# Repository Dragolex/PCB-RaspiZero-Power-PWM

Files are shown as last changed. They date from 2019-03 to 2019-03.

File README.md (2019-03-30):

# PCB-RaspiZero-Power-PWM
My first mostly successful try at a printed circuit board. It hosts a PCA9685 16xPWM generator and mosfets for every channel.
Controled via I2C from a Raspberry PI or an Adruino it can be used to dim loads of 7A and more. 
The board's shape, pins and hole palcement equals a Raspberry Pi Zero and therefore allows to mount it directly ontop and still use all pins.  
The Mosfets are N channel mosfets meaning only the Ground is common for all of them and on the PCB. Therefore loads of different voltages can be used simultaneously.

**The project can be opened with Eagle 9.1.1 or newer (importing into odler versions should be possible too).**

Boards based on Gerber files exported from this project have been produced by https://jlcpcb.com/
Samples have been soldered by myself and tested successfully with a bunch of different loads. Unfortunately it turned out that the diodes on the backside of the PCB are efectively useless because not sensefully placed in the scheme. Therefore inductive loads like motors still require separate flyback diodes!

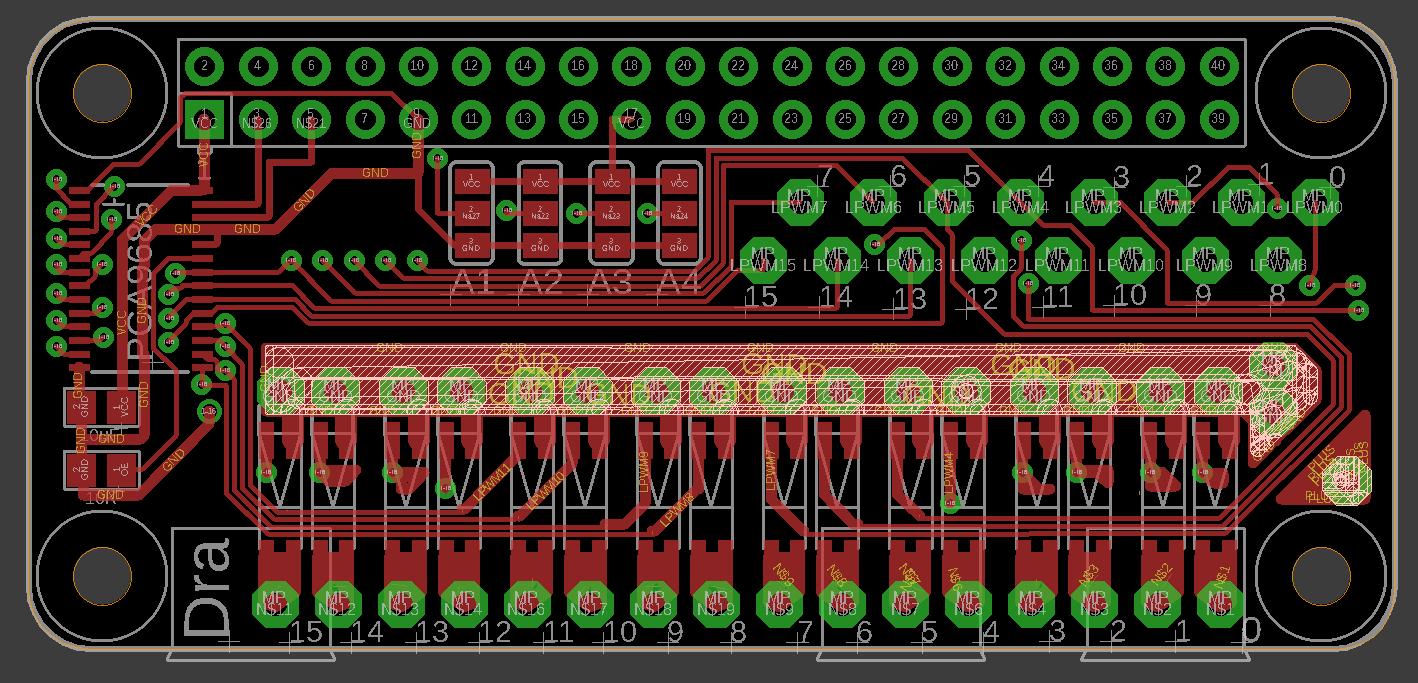
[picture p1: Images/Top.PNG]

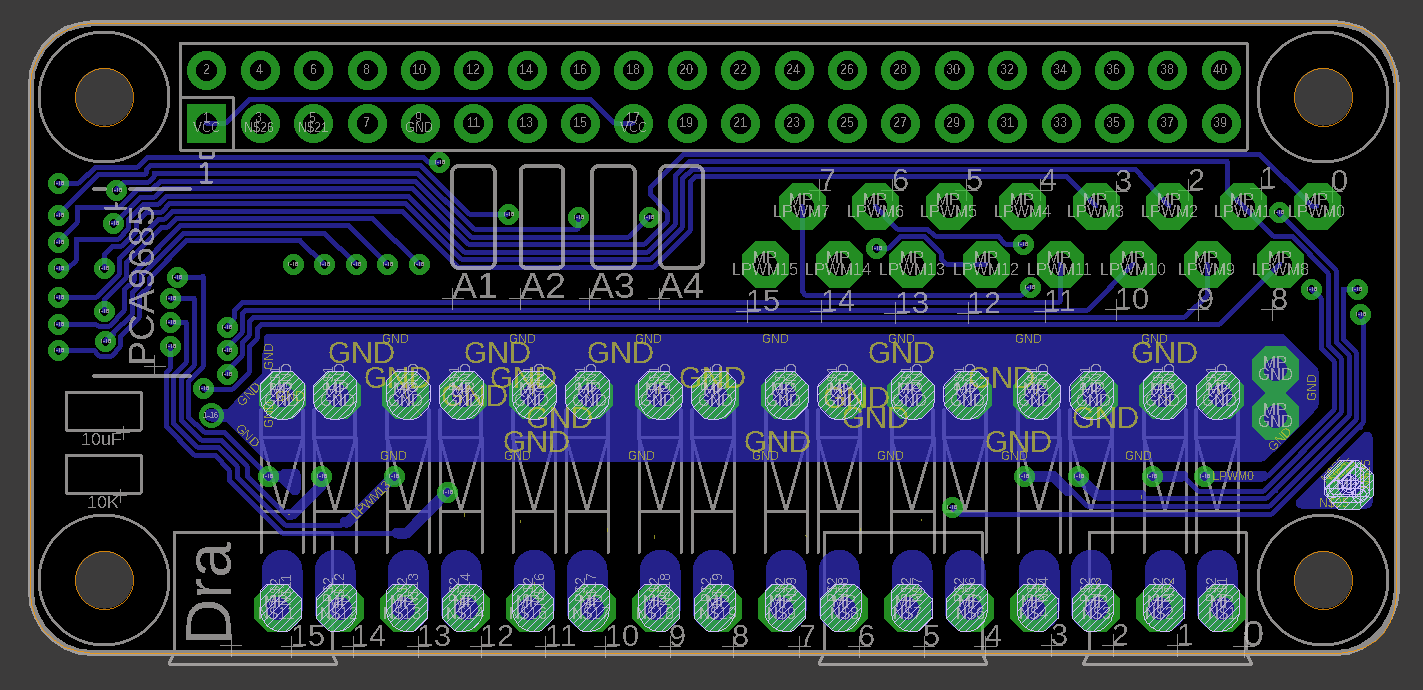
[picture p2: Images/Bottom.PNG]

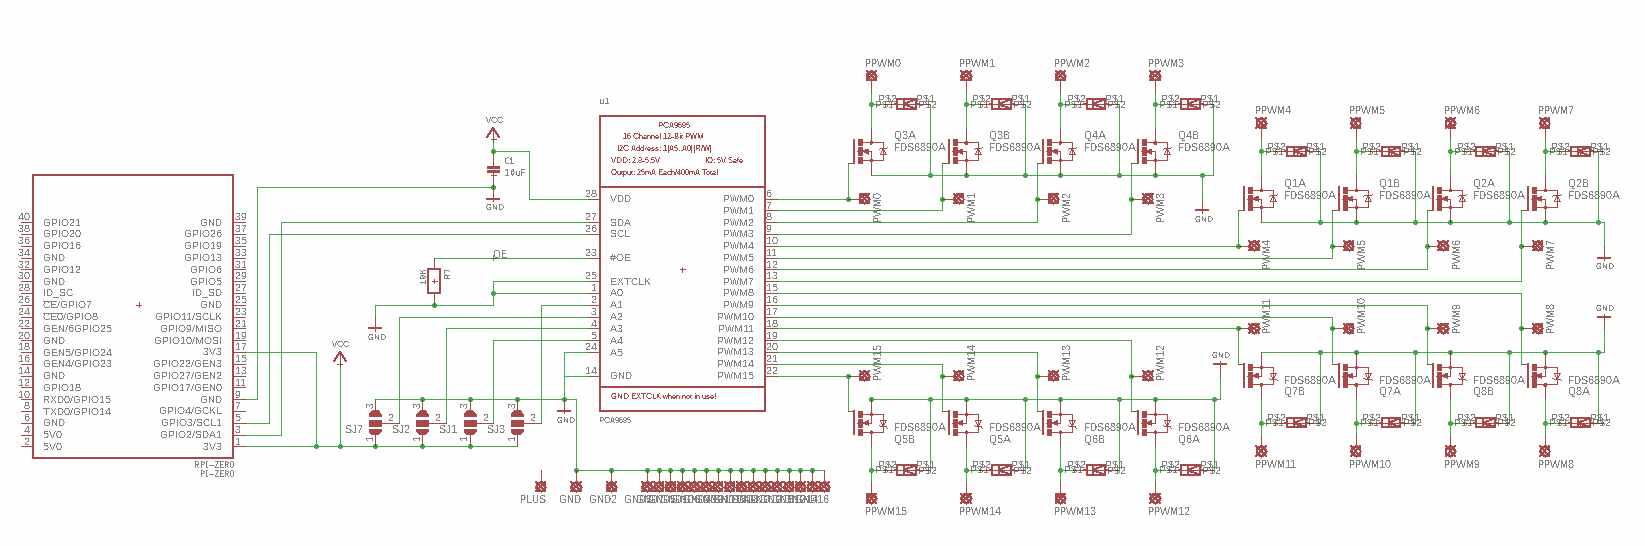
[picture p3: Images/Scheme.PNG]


Photos of a project using this comes soon.

## Credits
The PCA9685 and Raspberry scheme footprints are from Adafruit:
https://learn.adafruit.com/16-channel-pwm-servo-driver/downloads

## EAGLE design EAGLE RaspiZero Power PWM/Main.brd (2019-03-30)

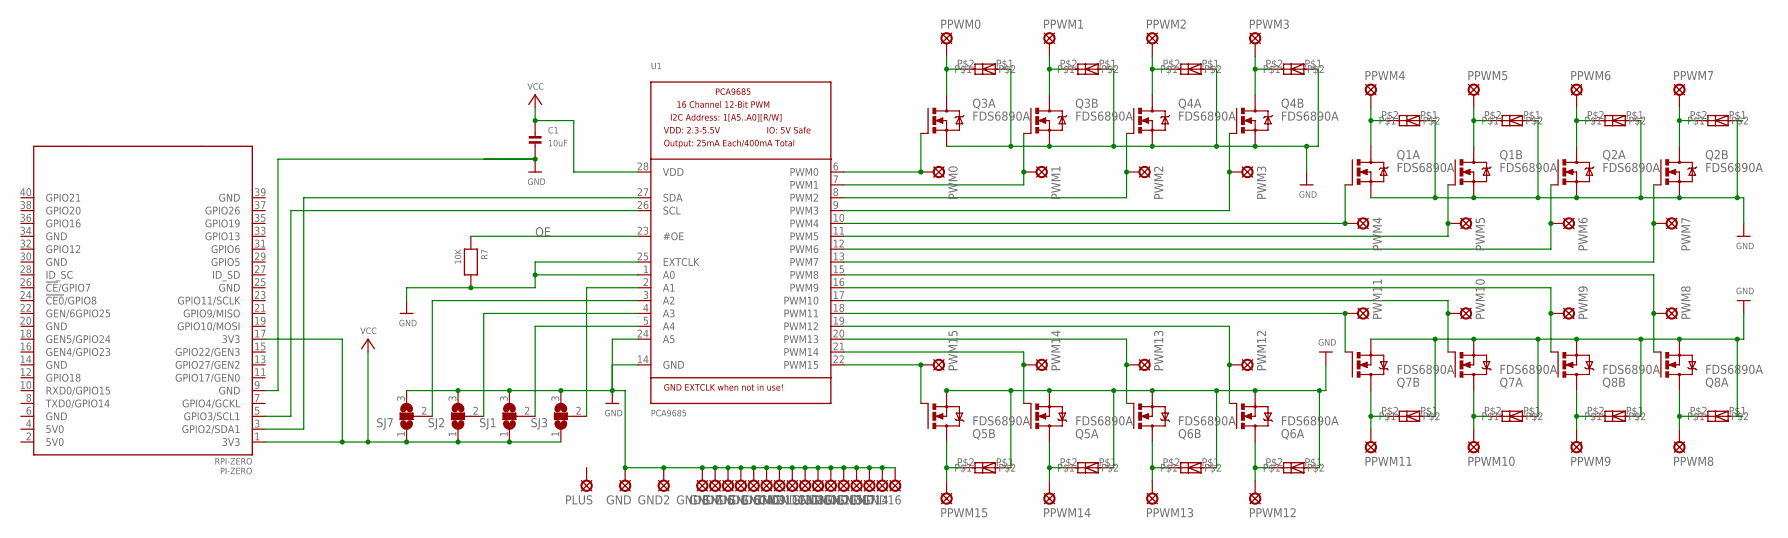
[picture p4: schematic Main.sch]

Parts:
C1: 10uF; 0805
GND, GND1, GND2, GND3, GND4, GND5, GND6, GND7, GND8, GND9, GND10, GND11, GND12, GND13, GND14, GND15, GND16, GND17: LSP11
PI-ZERO: RPI-ZERO; RASPBERRYPI_BASTELSTUBE_V13_RASPI_BOARD_B+_FULL
PLUS: LSP11
PPWM0, PPWM1, PPWM2, PPWM3, PPWM4, PPWM5, PPWM6, PPWM7, PPWM8, PPWM9, PPWM10, PPWM11, PPWM12, PPWM13, PPWM14, PPWM15: LSP11
PWM0, PWM1, PWM2, PWM3, PWM4, PWM5, PWM6, PWM7, PWM8, PWM9, PWM10, PWM11, PWM12, PWM13, PWM14, PWM15: LSP11
Q1, Q2, Q3, Q4, Q5, Q6, Q7, Q8: FDS6890A; M08A
R7: 10K; 0805
SJ1, SJ2, SJ3, SJ7: SJ2W; SJ_2
U1: PCA9685; MICROBUILDER_TSSOP28
U$6, U$7, U$8, U$9, U$10, U$11, U$12, U$13, U$14, U$15, U$16, U$17, U$18, U$19, U$20, U$21: OPTIONALDIODE

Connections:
GND: C1.2, GND.MP, GND1.MP, GND2.MP, GND3.MP, GND4.MP, GND5.MP, GND6.MP, GND7.MP, GND8.MP, GND9.MP, GND10.MP, GND11.MP, GND12.MP, GND13.MP, GND14.MP, GND15.MP, GND16.MP, GND17.MP, PI-ZERO.9 (GND), Q1.1 (S), Q1.3 (S), Q2.1 (S), Q2.3 (S), Q3.1 (S), Q3.3 (S), Q4.1 (S), Q4.3 (S), Q5.1 (S), Q5.3 (S), Q6.1 (S), Q6.3 (S), Q7.1 (S), Q7.3 (S), Q8.1 (S), Q8.3 (S), R7.2, SJ1.3, SJ2.3, SJ3.3, SJ7.3, U1.1 (A0), U1.14 (GND), U1.24 (A5), U1.25 (EXTCLK), U$6.P$1, U$7.P$1, U$8.P$1, U$9.P$1, U$10.P$1, U$11.P$1, U$12.P$1, U$13.P$1, U$14.P$1, U$15.P$1, U$16.P$1, U$17.P$1, U$18.P$1, U$19.P$1, U$20.P$1, U$21.P$1
LPWM0: PWM0.MP, Q3.2 (G), U1.6 (PWM0)
LPWM1: PWM1.MP, Q3.4 (G), U1.7 (PWM1)
LPWM2: PWM2.MP, Q4.2 (G), U1.8 (PWM2)
LPWM3: PWM3.MP, Q4.4 (G), U1.9 (PWM3)
LPWM4: PWM4.MP, Q1.2 (G), U1.10 (PWM4)
LPWM5: PWM5.MP, Q1.4 (G), U1.11 (PWM5)
LPWM6: PWM6.MP, Q2.2 (G), U1.12 (PWM6)
LPWM7: PWM7.MP, Q2.4 (G), U1.13 (PWM7)
LPWM8: PWM8.MP, Q8.2 (G), U1.15 (PWM8)
LPWM9: PWM9.MP, Q8.4 (G), U1.16 (PWM9)
LPWM10: PWM10.MP, Q7.2 (G), U1.17 (PWM10)
LPWM11: PWM11.MP, Q7.4 (G), U1.18 (PWM11)
LPWM12: PWM12.MP, Q6.2 (G), U1.19 (PWM12)
LPWM13: PWM13.MP, Q6.4 (G), U1.20 (PWM13)
LPWM14: PWM14.MP, Q5.2 (G), U1.21 (PWM14)
LPWM15: PWM15.MP, Q5.4 (G), U1.22 (PWM15)
unnamed: PPWM0.MP, Q3.7 (D), Q3.8 (D), U$7.P$2
unnamed: PPWM1.MP, Q3.5 (D), Q3.6 (D), U$8.P$2
unnamed: PPWM2.MP, Q4.7 (D), Q4.8 (D), U$9.P$2
unnamed: PPWM3.MP, Q4.5 (D), Q4.6 (D), U$10.P$2
unnamed: PPWM4.MP, Q1.7 (D), Q1.8 (D), U$11.P$2
unnamed: PPWM5.MP, Q1.5 (D), Q1.6 (D), U$12.P$2
unnamed: PPWM6.MP, Q2.7 (D), Q2.8 (D), U$13.P$2
unnamed: PPWM7.MP, Q2.5 (D), Q2.6 (D), U$14.P$2
unnamed: PPWM15.MP, Q5.5 (D), Q5.6 (D), U$6.P$2
unnamed: PPWM14.MP, Q5.7 (D), Q5.8 (D), U$21.P$2
unnamed: PPWM13.MP, Q6.5 (D), Q6.6 (D), U$20.P$2
unnamed: PPWM12.MP, Q6.7 (D), Q6.8 (D), U$19.P$2
unnamed: PPWM11.MP, Q7.5 (D), Q7.6 (D), U$18.P$2
unnamed: PPWM10.MP, Q7.7 (D), Q7.8 (D), U$17.P$2
unnamed: PPWM9.MP, Q8.5 (D), Q8.6 (D), U$16.P$2
unnamed: PPWM8.MP, Q8.7 (D), Q8.8 (D), U$15.P$2
unnamed: PI-ZERO.5 (GPIO3/SCL1), U1.26 (SCL)
unnamed: SJ7.2, U1.3 (A2)
unnamed: SJ2.2, U1.4 (A3)
unnamed: SJ1.2, U1.5 (A4)
unnamed: PI-ZERO.3 (GPIO2/SDA1), U1.27 (SDA)
unnamed: SJ3.2, U1.2 (A1)
OE: R7.1, U1.23 (#OE)
VCC: C1.1, PI-ZERO.1 (3V3), PI-ZERO.17 (3V3), SJ1.1, SJ2.1, SJ3.1, SJ7.1, U1.28 (VDD)

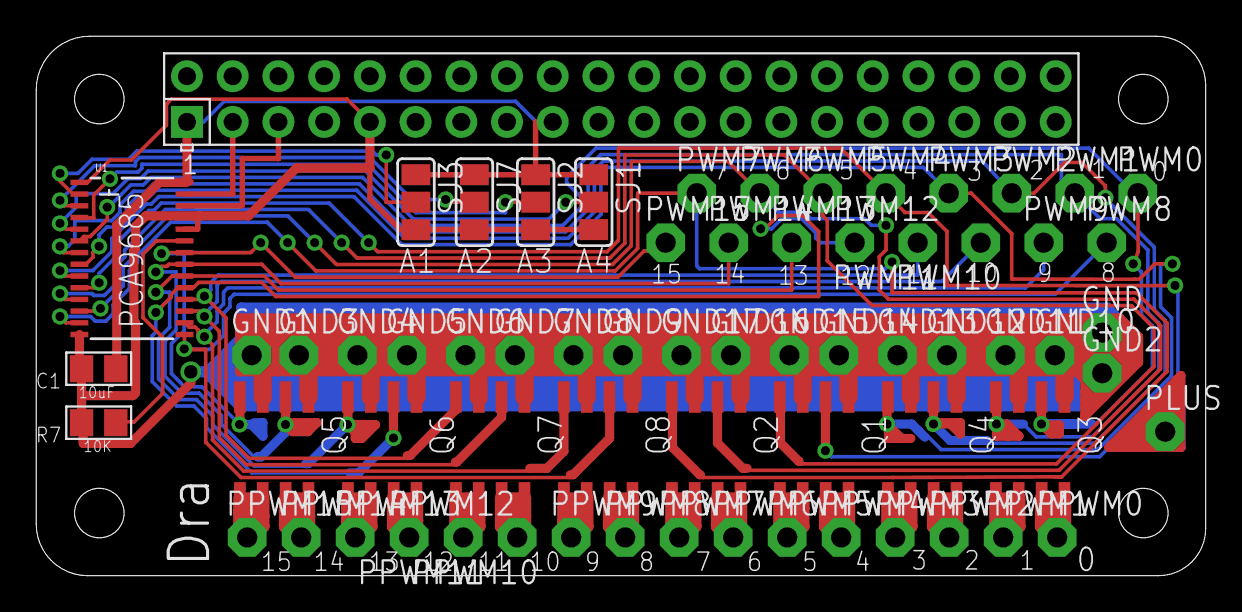
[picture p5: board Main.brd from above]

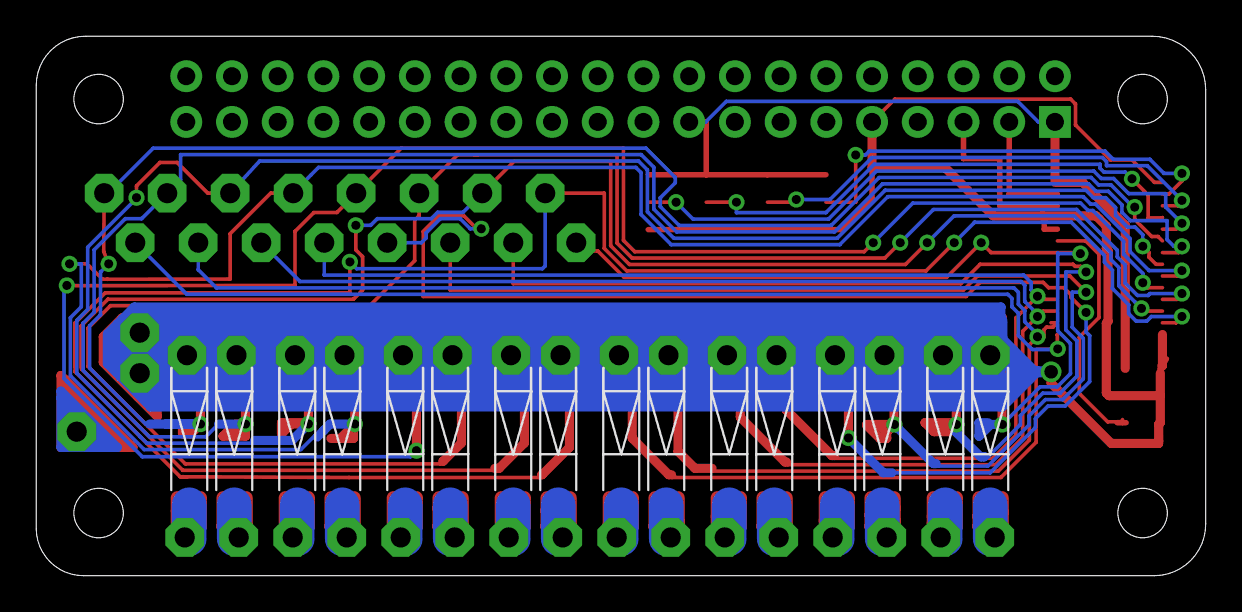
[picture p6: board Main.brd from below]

Board: 2 copper layers, 65.0 x 30.0 mm, 83 parts (16 on the bottom side), 41 nets.

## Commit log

2019-03-30 Eagle Files
    [Main.brd, Main.sch]
2019-03-30 Gerber files
    [copper_bottom.gbr, copper_top.gbr, drills.xln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]
